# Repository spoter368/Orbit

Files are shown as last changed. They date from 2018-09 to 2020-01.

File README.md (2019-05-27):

# Orbit keyboard
A split ergonomic keyboard for all

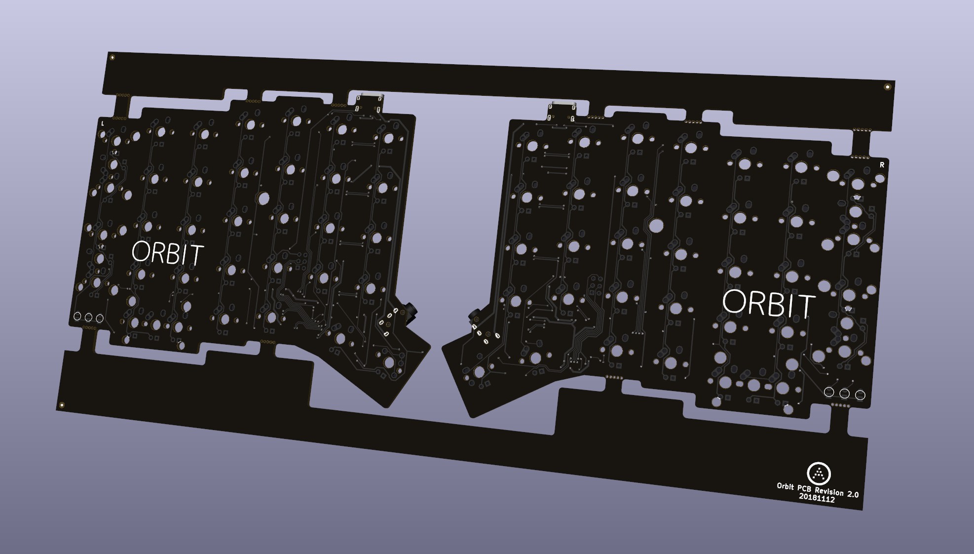
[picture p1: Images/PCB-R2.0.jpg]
Render Image


#### In light of recent claims that I am 100% liable for any of my open source PCBs, I am adding this disclaimer.
#### I provide these PCBs as a reference for designing keyboard PCBs. Using them within your projects will require a will to do research of one's own and to learn the workings of them, potentially fixing issues if they exist.
# I provide these PCBs without liability and without any guarantees regarding functionality, as expressed in the licenses under which these PCBs are licensed.

## Features
- Ergonomic layout based on the [crkbd](https://github.com/foostan/crkbd)
- All on-board components; no separate controller board
- USB Type-C and in-switch backlight
- Alps SKCL/M and MX compatibility
- Built-in overcurrent, reverse voltage, and ESD protection.
- Pre-panelized in a single PCB file for easy production
- Keyboard-Layout-Editor data is available [here](http://www.keyboard-layout-editor.com/#/gists/53ebf59524de12515cb7e2e6de94f0d6).

## Designed for all
- This keyboard remains close to typical QWERTY layout in key positioning.
- Most keys remain in their typical locations, which allows easy migration from standard layout keyboards.
- Whether new to ergonomic layouts or already an avid adopter, Orbit will suit your needs.

## Electrical side
- The incoming power is handled as shown:
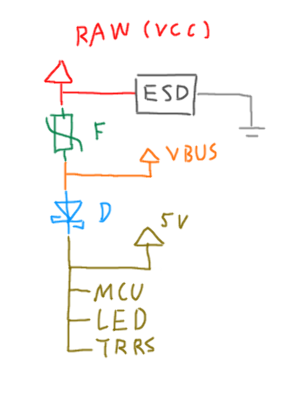
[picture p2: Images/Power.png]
Diagram

- VCC/Raw is the raw power fed through the USB connector. The ESD protection IC is bound to here.
- VBUS is "stable raw power" after being passed through a polyfuse. Used for upstream detection, for a downstream Schottky diode prevents flow from 5V into VBUS. In other words, VBUS is only at 5V when fed from upstream USB.
- 5V is the "stable power" after passing through a Schottky diode. Used for powering MCU, LEDs, and other split half. Power from the other half feeds here, for it has already been filtered on the other side.
- Measures are taken to isolate the LED, MCU, and split connection 5V as upstream as possible to prevent interference.

## Aesthetics
- Ground plane is limited to critical parts for aesthetic reasons.
- Top side of PCB is mostly covered with soldermask.

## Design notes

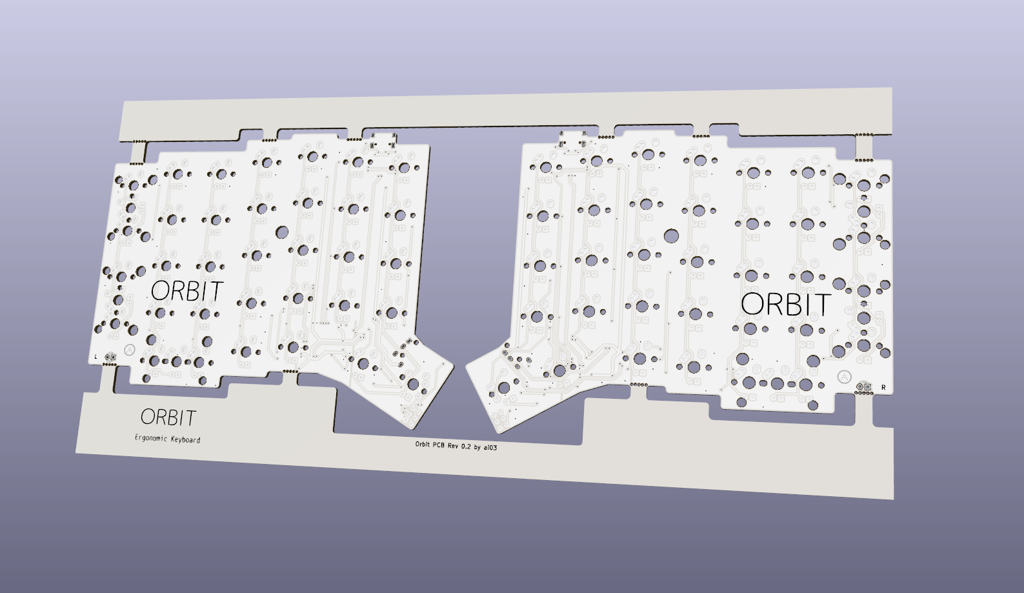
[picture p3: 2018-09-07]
Images/Render.png

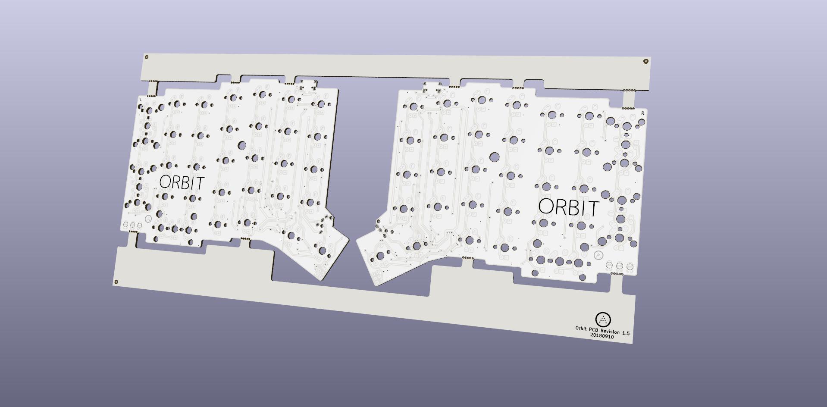
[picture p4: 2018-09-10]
Images/PCB-R1.5.jpg

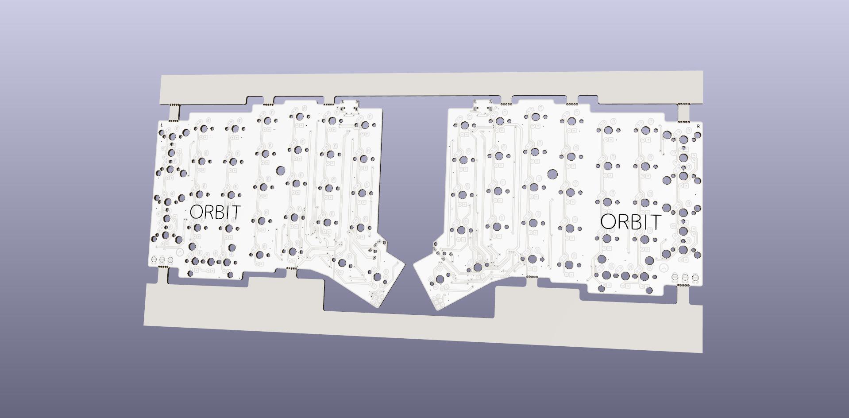
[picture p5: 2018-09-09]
Images/PCB-R1.2.jpg

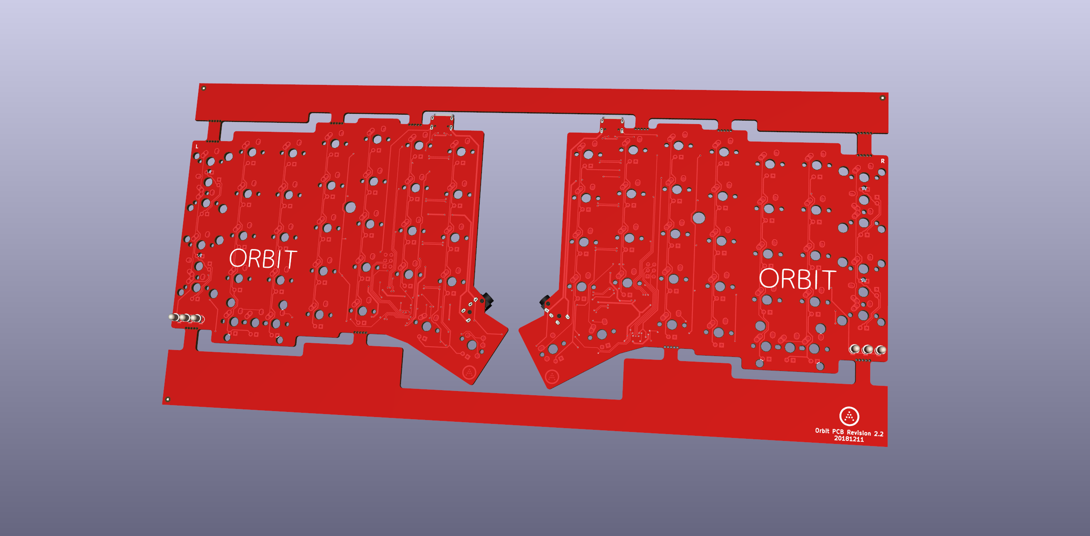
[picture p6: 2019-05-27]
Orbit-PCB/render.png

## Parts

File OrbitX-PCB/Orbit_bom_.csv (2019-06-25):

Component | Description | Part | References | Value | Footprint | Quantity Per PCB | Datasheet
1 | Unpolarized capacitor, small symbol | C_Small | C4 C5 C6 C11 C12 C13 | 0.1uF | C_0603_1608Metric | 6 | ~
2 | Unpolarized capacitor, small symbol | C_Small | C7 C14 | 10uF | C_0603_1608Metric | 2 | ~
3 | Unpolarized capacitor, small symbol | C_Small | C3 C10 | 1uF | C_0603_1608Metric | 2 | ~
4 | Unpolarized capacitor, small symbol | C_Small | C1 C2 C8 C9 | 22pF | C_0603_1608Metric | 4 | ~
5 | Diode, small symbol | D_Small | D1 D2 D3 D4 D5 D6 D7 D8 D9 D10 D11 D12 D13 D14 D15 D16 D17 D18 D19 D20 D21 D22 D23 D24 D25 D26 D27 D28 D29 D30 D31 D32 D33 D34 D35 D36 D37 D38 D39 D40 D41 D42 D43 D44 D45 D46 D47 D48 | SOD123 | D_SOD-123 | 48 | ~
6 | Schottky diode, small symbol | D_Schottky_Small | D75 D76 | Schottky | D_SOD-123 | 2 | ~
7 | Resettable fuse, polymeric positive temperature coefficient, small symbol | Polyfuse_Small | F1 F2 | 500mA | Fuse_1206_3216Metric | 2 | ~
8 | Generic connector, single row, 01x04, script generated (kicad-library-utils/schlib/autogen/connector/) | Conn_01x04 | J1 J11 | PJ-3200B-4A | PJ-3200B-4A | 2 | ~
9 | Resistor, small symbol | R_Small | R25 R67 R87 R88 | 10k | R_0603_1608Metric | 4 | ~
10 | Resistor, small symbol | R_Small | R41 R42 R83 R84 | 22 | R_0603_1608Metric | 4 | ~
11 | Resistor, small symbol | R_Small | R9 R10 | 4.7k | R_0603_1608Metric | 2 | ~
12 | Resistor, small symbol | R_Small | R43 R44 R85 R86 | 5.1k | R_0603_1608Metric | 4 | ~
13 | Push button switch, generic, two pins | SW_Push | SW1 SW2 | SW_Push | SKQGADE010 | 2
14 | 16MHz, 16kB Flash, 1.25kB SRAM, 512B EEPROM, USB 2.0, QFN-44 | ATmega32U4-MU | U1 U3 | ATmega32U4-MU | QFN-44-1EP_7x7mm_P0.5mm_EP5.2x5.2mm | 2 | http://ww1.microchip.com/downloads/en/DeviceDoc/Atmel-7766-8-bit-AVR-ATmega16U4-32U4_Datasheet.pdf
15 |  | PRTR5V0U2X | U2 U4 | PRTR5V0U2X | SOT143B | 2
16 |  | HRO-TYPE-C-31-M-12 | USB1 USB2 | HRO-TYPE-C-31-M-12 | HRO-TYPE-C-31-M-12-Assembly | 2
17 | Four pin crystal, GND on pins 2 and 4, small symbol | Crystal_GND24_Small | Y1 Y2 | 16MHz | Crystal_SMD_3225-4Pin_3.2x2.5mm | 2 | ~
Component Groups: | 17
Component Count: | 92
Fitted Components: | 92
Number of PCBs: | 1
Total components: | 92
Schematic Version:
Schematic Date:
BoM Date: | 6/25/2019 7:16:13 PM
Schematic Source: | C:\Users\Ryota\Documents\GitHub\Orbit\OrbitX-PCB\Orbit.sch
KiCad Version: | Eeschema (5.1.2)-1

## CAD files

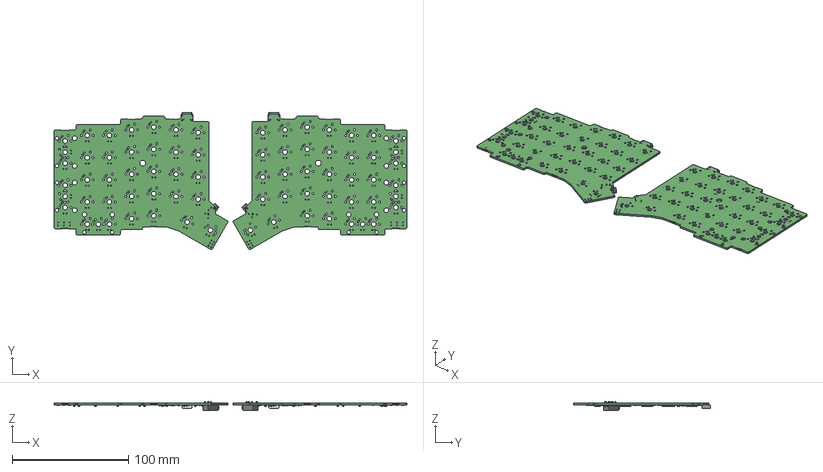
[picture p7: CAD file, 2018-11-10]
OrbitX-PCB/Orbit.step
303.2 x 117.9 x 8.00 mm

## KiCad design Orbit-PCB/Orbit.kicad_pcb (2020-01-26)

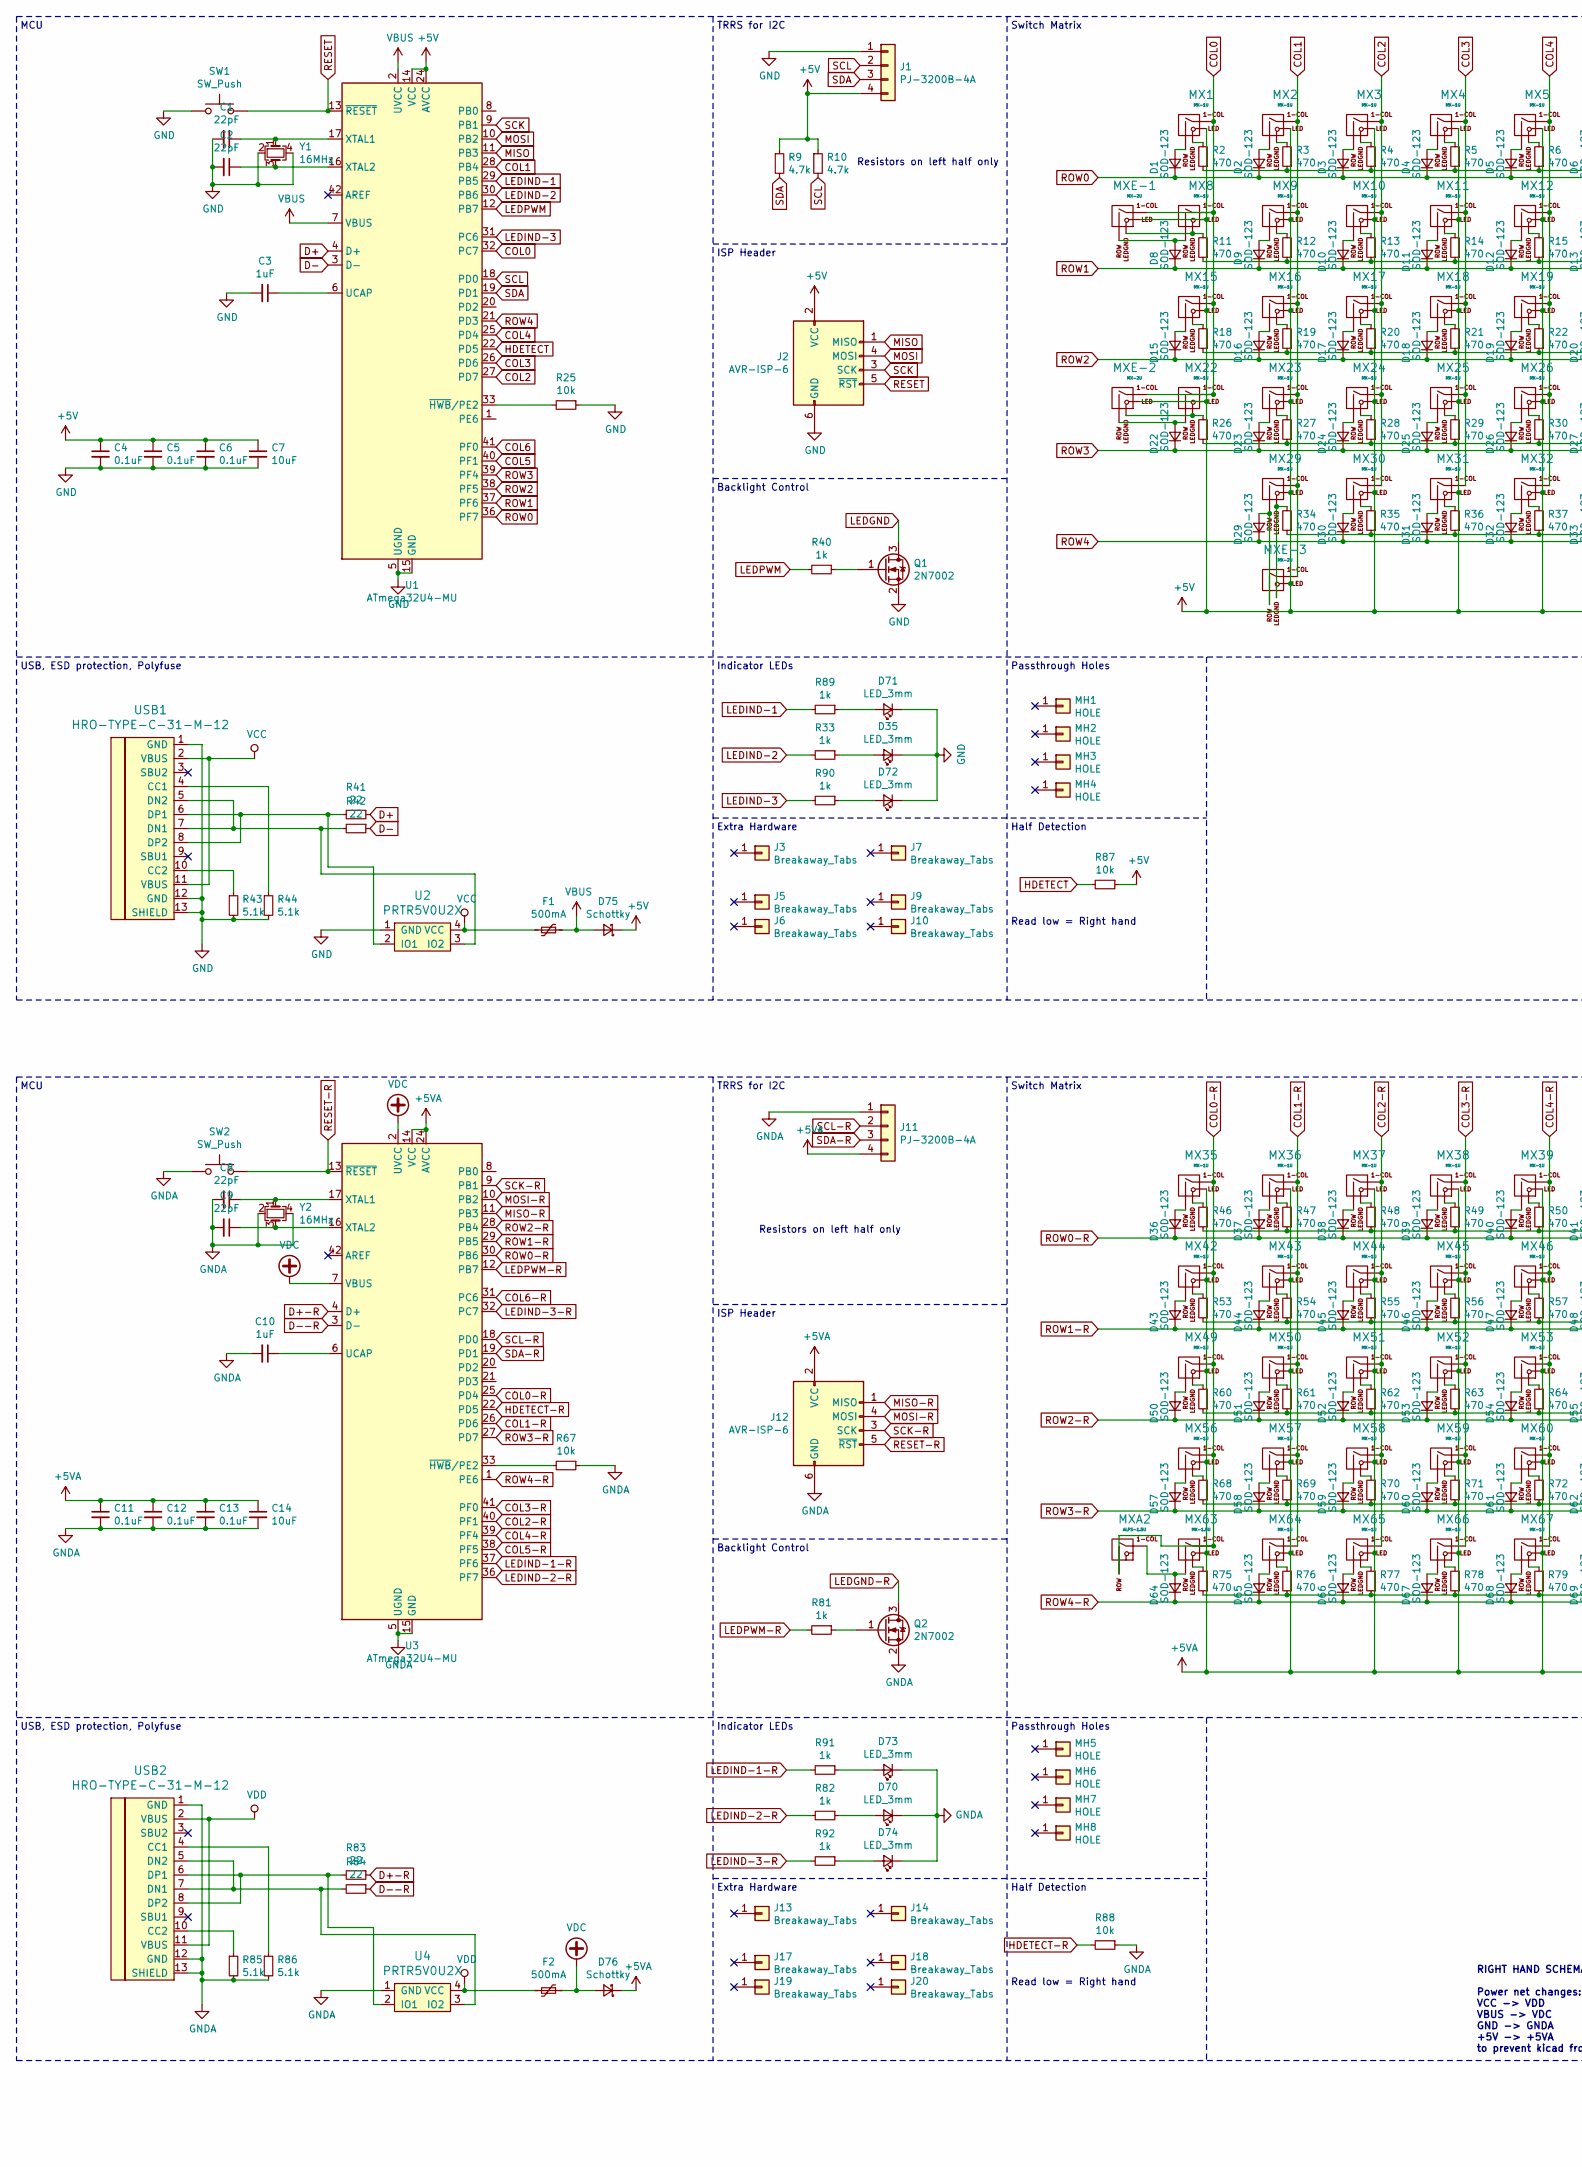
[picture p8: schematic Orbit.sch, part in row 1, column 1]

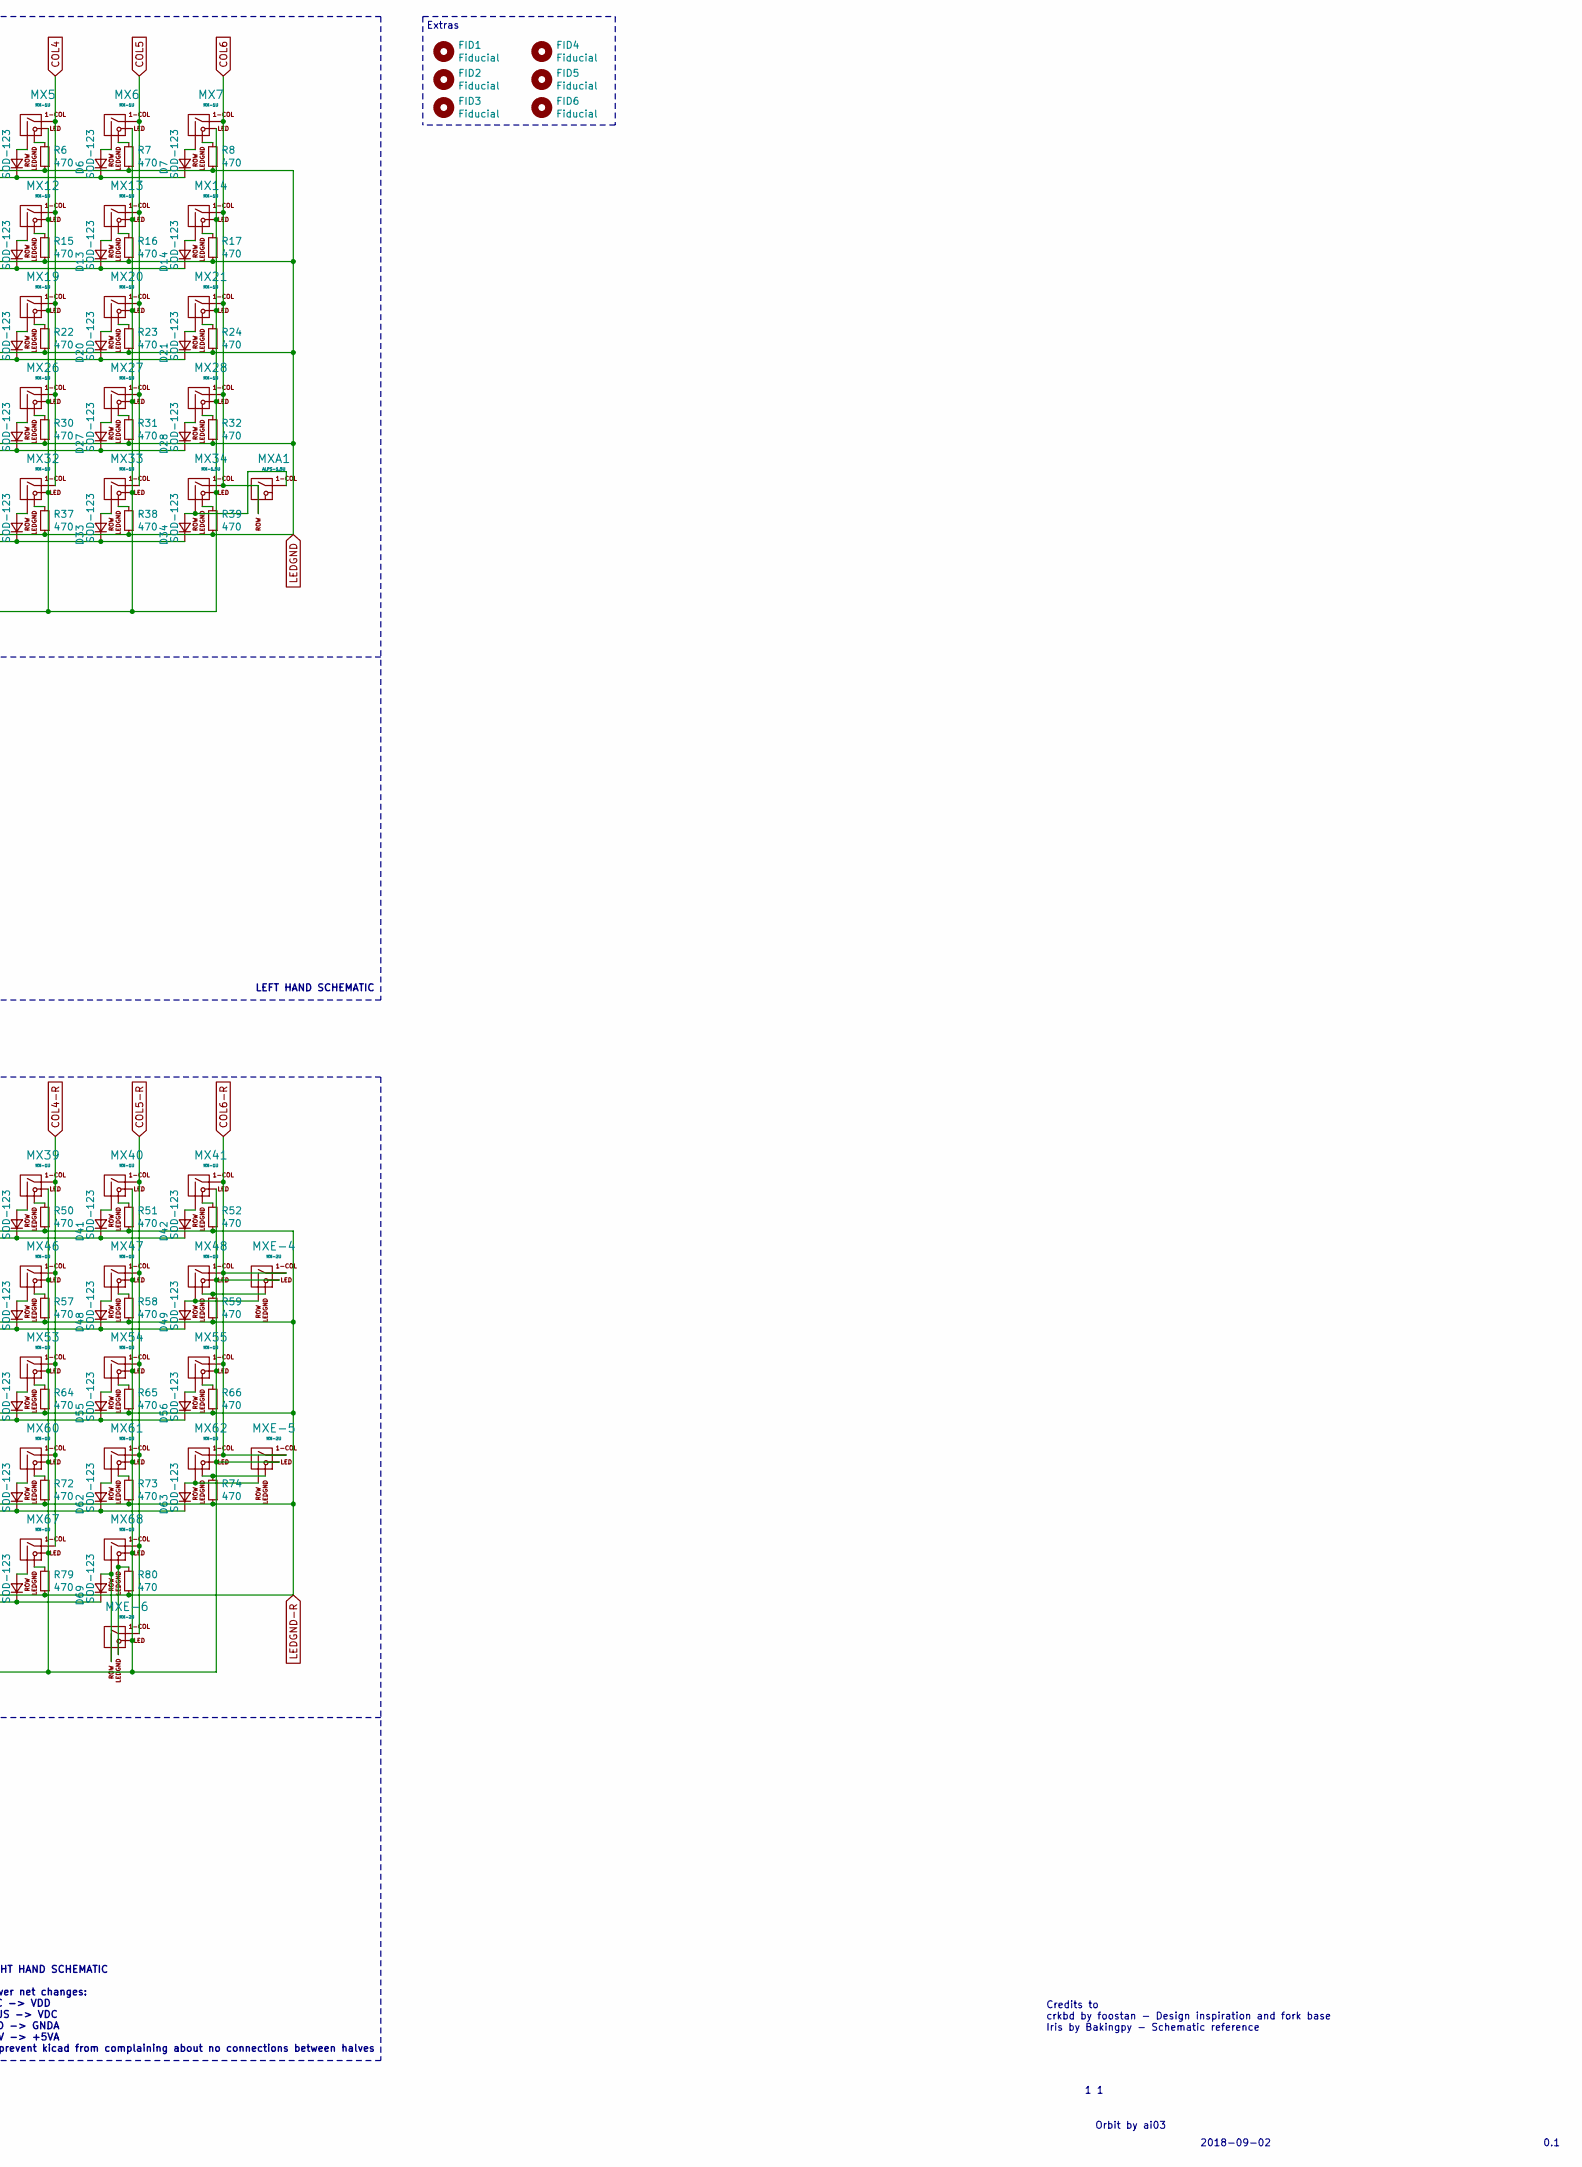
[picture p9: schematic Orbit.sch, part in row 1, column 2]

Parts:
C1, C2, C8, C9: 22pF; C_0603_1608Metric
C3, C10: 1uF; C_0603_1608Metric
C4, C5, C6, C11, C12, C13: 0.1uF; C_0603_1608Metric
C7, C14: 10uF; C_0603_1608Metric
D1, D2, D3, D4, D5, D6, D7, D8, D9, D10, D11, D12, D13, D14, D15, D16, D17, D18, D19, D20, D21, D22, D23, D24, D25, D26, D27, D28, D29, D30, D31, D32, D33, D34, D36, D37, D38, D39, D40, D41, D42, D43, D44, D45, D46, D47, D48, D49, D50, D51, D52, D53, D54, D55, D56, D57, D58, D59, D60, D61, D62, D63, D64, D65, D66, D67, D68, D69: SOD-123; D_SOD-123
D35, D70, D71, D72, D73, D74: LED_3mm; LED_D3.0mm
D75, D76: Schottky; D_SOD-123
F1, F2: 500mA; Fuse_SMD1206_Reflow
FID1, FID2, FID3, FID4, FID5, FID6: Fiducial; Fiducial_1mm_Dia_2.54mm_Outer_CopperTop
J1, J11: PJ-3200B-4A
J2, J12: AVR-ISP-6; Reset_Pretty
J3, J5, J6, J7, J9, J10, J13, J14, J17, J18, J19, J20: Breakaway_Tabs; breakaway-mousebites
MH1, MH2, MH3, MH4, MH5, MH6, MH7, MH8: HOLE; MountingHole_3.2mm_M3_ISO7380
MX1, MX2, MX3, MX4, MX5, MX6, MX7, MX8, MX9, MX10, MX11, MX12, MX13, MX14, MX15, MX16, MX17, MX18, MX19, MX20, MX21, MX22, MX23, MX24, MX25, MX26, MX27, MX28, MX29, MX30, MX31, MX32, MX33, MX35, MX36, MX37, MX38, MX39, MX40, MX41, MX42, MX43, MX44, MX45, MX46, MX47, MX48, MX49, MX50, MX51, MX52, MX53, MX54, MX55, MX56, MX57, MX58, MX59, MX60, MX61, MX62, MX64, MX65, MX66, MX67, MX68: MX-1U
MX34, MX63: MX-1.5U; MXOnly-1.5U-Vertical
MXA1, MXA2: ALPS-1.5U
MXE-1, MXE-2: MX-2U
MXE-3, MXE-4, MXE-5, MXE-6: MX-2U; MX-2U-ReversedStabilizers
Q1, Q2: 2N7002; SOT-23
R2, R3, R4, R5, R6, R7, R8, R11, R12, R13, R14, R15, R16, R17, R18, R19, R20, R21, R22, R23, R24, R26, R27, R28, R29, R30, R31, R32, R34, R35, R36, R37, R38, R39, R46, R47, R48, R49, R50, R51, R52, R53, R54, R55, R56, R57, R58, R59, R60, R61, R62, R63, R64, R65, R66, R68, R69, R70, R71, R72, R73, R74, R75, R76, R77, R78, R79, R80: 470; R_0805_2012Metric
R9, R10: 4.7k; R_0805_2012Metric
R25, R67, R87, R88: 10k; R_0805_2012Metric
R33, R40, R81, R82, R89, R90, R91, R92: 1k; R_0805_2012Metric
R41, R42, R83, R84: 22; R_0805_2012Metric
R43, R44, R85, R86: 5.1k; R_0805_2012Metric
SW1, SW2: SW_Push; SKQGADE010
U1, U3: ATmega32U4-MU; QFN-44-1EP_7x7mm_Pitch0.5mm
U2, U4: PRTR5V0U2X; SOT143B
USB1, USB2: HRO-TYPE-C-31-M-12; HRO-TYPE-C-31-M-12-Assembly
Y1, Y2: 16MHz; Crystal_SMD_3225-4pin_3.2x2.5mm

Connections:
+5V: C4.1, C5.1, C6.1, C7.1, D75.1 (K), J1.4, J2.2 (VCC), MX1.3 (LED), MX2.3 (LED), MX3.3 (LED), MX4.3 (LED), MX5.3 (LED), MX6.3 (LED), MX7.3 (LED), MX8.3 (LED), MX9.3 (LED), MX10.3 (LED), MX11.3 (LED), MX12.3 (LED), MX13.3 (LED), MX14.3 (LED), MX15.3 (LED), MX16.3 (LED), MX17.3 (LED), MX18.3 (LED), MX19.3 (LED), MX20.3 (LED), MX21.3 (LED), MX22.3 (LED), MX23.3 (LED), MX24.3 (LED), MX25.3 (LED), MX26.3 (LED), MX27.3 (LED), MX28.3 (LED), MX29.3 (LED), MX30.3 (LED), MX31.3 (LED), MX32.3 (LED), MX33.3 (LED), MX34.3 (LED), MXE-1.3 (LED), MXE-2.3 (LED), MXE-3.3 (LED), R9.1, R10.1, R87.1, U1.14 (VCC), U1.24 (AVCC), U1.34 (VCC), U1.44 (AVCC)
+5VA: C11.1, C12.1, C13.1, C14.1, D76.1 (K), J11.4, J12.2 (VCC), MX35.3 (LED), MX36.3 (LED), MX37.3 (LED), MX38.3 (LED), MX39.3 (LED), MX40.3 (LED), MX41.3 (LED), MX42.3 (LED), MX43.3 (LED), MX44.3 (LED), MX45.3 (LED), MX46.3 (LED), MX47.3 (LED), MX48.3 (LED), MX49.3 (LED), MX50.3 (LED), MX51.3 (LED), MX52.3 (LED), MX53.3 (LED), MX54.3 (LED), MX55.3 (LED), MX56.3 (LED), MX57.3 (LED), MX58.3 (LED), MX59.3 (LED), MX60.3 (LED), MX61.3 (LED), MX62.3 (LED), MX63.3 (LED), MX64.3 (LED), MX65.3 (LED), MX66.3 (LED), MX67.3 (LED), MX68.3 (LED), MXE-4.3 (LED), MXE-5.3 (LED), MXE-6.3 (LED), U3.14 (VCC), U3.24 (AVCC), U3.34 (VCC), U3.44 (AVCC)
COL0: MX1.1 (COL), MX8.1 (COL), MX15.1 (COL), MX22.1 (COL), MXE-1.1 (COL), MXE-2.1 (COL), U1.32 (PC7)
COL0-R: MX35.1 (COL), MX42.1 (COL), MX49.1 (COL), MX56.1 (COL), MX63.1 (COL), MXA2.2 (ROW), U3.25 (PD4)
COL1: MX2.1 (COL), MX9.1 (COL), MX16.1 (COL), MX23.1 (COL), MX29.1 (COL), MXE-3.1 (COL), U1.28 (PB4)
COL1-R: MX36.1 (COL), MX43.1 (COL), MX50.1 (COL), MX57.1 (COL), MX64.1 (COL), U3.26 (PD6)
COL2: MX3.1 (COL), MX10.1 (COL), MX17.1 (COL), MX24.1 (COL), MX30.1 (COL), U1.27 (PD7)
COL2-R: MX37.1 (COL), MX44.1 (COL), MX51.1 (COL), MX58.1 (COL), MX65.1 (COL), U3.40 (PF1)
COL3: MX4.1 (COL), MX11.1 (COL), MX18.1 (COL), MX25.1 (COL), MX31.1 (COL), U1.26 (PD6)
COL3-R: MX38.1 (COL), MX45.1 (COL), MX52.1 (COL), MX59.1 (COL), MX66.1 (COL), U3.41 (PF0)
COL4: MX5.1 (COL), MX12.1 (COL), MX19.1 (COL), MX26.1 (COL), MX32.1 (COL), U1.25 (PD4)
COL4-R: MX39.1 (COL), MX46.1 (COL), MX53.1 (COL), MX60.1 (COL), MX67.1 (COL), U3.39 (PF4)
COL5: MX6.1 (COL), MX13.1 (COL), MX20.1 (COL), MX27.1 (COL), MX33.1 (COL), U1.40 (PF1)
COL5-R: MX40.1 (COL), MX47.1 (COL), MX54.1 (COL), MX61.1 (COL), MX68.1 (COL), MXE-6.1 (COL), U3.38 (PF5)
COL6: MX7.1 (COL), MX14.1 (COL), MX21.1 (COL), MX28.1 (COL), MX34.1 (COL), MXA1.2 (ROW), U1.41 (PF0)
COL6-R: MX41.1 (COL), MX48.1 (COL), MX55.1 (COL), MX62.1 (COL), MXE-4.1 (COL), MXE-5.1 (COL), U3.31 (PC6)
D+: R41.1, U1.4 (D+)
D+-R: R83.1, U3.4 (D+)
D-: R42.1, U1.3 (D-)
D--R: R84.1, U3.3 (D-)
GND: C1.2, C2.2, C3.2, C4.2, C5.2, C6.2, C7.2, D35.1 (K), D71.1 (K), D72.1 (K), J1.1, J2.6 (GND), Q1.2 (S), R25.1, R43.2, R44.2, SW1.1, U1.5 (UGND), U1.15 (GND), U1.23 (GND), U1.35 (GND), U1.43 (GND), U1.45 (GND), U2.1 (GND), USB1.1 (GND), USB1.12 (GND), USB1.13 (SHIELD), Y1.2, Y1.4
GNDA: C8.2, C9.2, C10.2, C11.2, C12.2, C13.2, C14.2, D70.1 (K), D73.1 (K), D74.1 (K), J11.1, J12.6 (GND), Q2.2 (S), R67.1, R85.2, R86.2, R88.1, SW2.1, U3.5 (UGND), U3.15 (GND), U3.23 (GND), U3.35 (GND), U3.43 (GND), U3.45 (GND), U4.1 (GND), USB2.1 (GND), USB2.12 (GND), USB2.13 (SHIELD), Y2.2, Y2.4
HDETECT: R87.2, U1.22 (PD5)
HDETECT-R: R88.2, U3.22 (PD5)
LEDGND: Q1.3 (D), R2.1, R3.1, R4.1, R5.1, R6.1, R7.1, R8.1, R11.1, R12.1, R13.1, R14.1, R15.1, R16.1, R17.1, R18.1, R19.1, R20.1, R21.1, R22.1, R23.1, R24.1, R26.1, R27.1, R28.1, R29.1, R30.1, R31.1, R32.1, R34.1, R35.1, R36.1, R37.1, R38.1, R39.1
LEDGND-R: Q2.3 (D), R46.1, R47.1, R48.1, R49.1, R50.1, R51.1, R52.1, R53.1, R54.1, R55.1, R56.1, R57.1, R58.1, R59.1, R60.1, R61.1, R62.1, R63.1, R64.1, R65.1, R66.1, R68.1, R69.1, R70.1, R71.1, R72.1, R73.1, R74.1, R75.1, R76.1, R77.1, R78.1, R79.1, R80.1
LEDIND-1: R89.2, U1.29 (PB5)
LEDIND-1-R: R91.2, U3.37 (PF6)
LEDIND-2: R33.2, U1.30 (PB6)
LEDIND-2-R: R82.2, U3.36 (PF7)
LEDIND-3: R90.2, U1.31 (PC6)
LEDIND-3-R: R92.2, U3.32 (PC7)
LEDPWM: R40.2, U1.12 (PB7)
LEDPWM-R: R81.2, U3.12 (PB7)
MISO: J2.1 (MISO), U1.11 (PB3)
MISO-R: J12.1 (MISO), U3.11 (PB3)
MOSI: J2.4 (MOSI), U1.10 (PB2)
MOSI-R: J12.4 (MOSI), U3.10 (PB2)
unnamed: C1.1, U1.17 (XTAL1), Y1.1
unnamed: C2.1, U1.16 (XTAL2), Y1.3
unnamed: C3.1, U1.6 (UCAP)
unnamed: C8.1, U3.17 (XTAL1), Y2.1
unnamed: C9.1, U3.16 (XTAL2), Y2.3
unnamed: C10.1, U3.6 (UCAP)
unnamed: D1.2 (A), MX1.2 (ROW)
unnamed: D2.2 (A), MX2.2 (ROW)
unnamed: D3.2 (A), MX3.2 (ROW)
unnamed: D4.2 (A), MX4.2 (ROW)
unnamed: D5.2 (A), MX5.2 (ROW)
unnamed: D6.2 (A), MX6.2 (ROW)
unnamed: D7.2 (A), MX7.2 (ROW)
unnamed: D8.2 (A), MX8.2 (ROW), MXE-1.2 (ROW)
unnamed: D9.2 (A), MX9.2 (ROW)
unnamed: D10.2 (A), MX10.2 (ROW)
unnamed: D11.2 (A), MX11.2 (ROW)
unnamed: D12.2 (A), MX12.2 (ROW)
unnamed: D13.2 (A), MX13.2 (ROW)
unnamed: D14.2 (A), MX14.2 (ROW)
unnamed: D15.2 (A), MX15.2 (ROW)
unnamed: D16.2 (A), MX16.2 (ROW)
unnamed: D17.2 (A), MX17.2 (ROW)
unnamed: D18.2 (A), MX18.2 (ROW)
unnamed: D19.2 (A), MX19.2 (ROW)
unnamed: D20.2 (A), MX20.2 (ROW)
unnamed: D21.2 (A), MX21.2 (ROW)
unnamed: D22.2 (A), MX22.2 (ROW), MXE-2.2 (ROW)
unnamed: D23.2 (A), MX23.2 (ROW)
unnamed: D24.2 (A), MX24.2 (ROW)
unnamed: D25.2 (A), MX25.2 (ROW)
unnamed: D26.2 (A), MX26.2 (ROW)
unnamed: D27.2 (A), MX27.2 (ROW)
unnamed: D28.2 (A), MX28.2 (ROW)
unnamed: D29.2 (A), MX29.2 (ROW), MXE-3.2 (ROW)
unnamed: D30.2 (A), MX30.2 (ROW)
unnamed: D31.2 (A), MX31.2 (ROW)
unnamed: D32.2 (A), MX32.2 (ROW)
unnamed: D33.2 (A), MX33.2 (ROW)
unnamed: D34.2 (A), MX34.2 (ROW), MXA1.1 (COL)
unnamed: D35.2 (A), R33.1
unnamed: D36.2 (A), MX35.2 (ROW)
unnamed: D37.2 (A), MX36.2 (ROW)
unnamed: D38.2 (A), MX37.2 (ROW)
unnamed: D39.2 (A), MX38.2 (ROW)
unnamed: D40.2 (A), MX39.2 (ROW)
unnamed: D41.2 (A), MX40.2 (ROW)
unnamed: D42.2 (A), MX41.2 (ROW)
unnamed: D43.2 (A), MX42.2 (ROW)
unnamed: D44.2 (A), MX43.2 (ROW)
unnamed: D45.2 (A), MX44.2 (ROW)
unnamed: D46.2 (A), MX45.2 (ROW)
unnamed: D47.2 (A), MX46.2 (ROW)
unnamed: D48.2 (A), MX47.2 (ROW)
unnamed: D49.2 (A), MX48.2 (ROW), MXE-4.2 (ROW)
unnamed: D50.2 (A), MX49.2 (ROW)
unnamed: D51.2 (A), MX50.2 (ROW)
unnamed: D52.2 (A), MX51.2 (ROW)
unnamed: D53.2 (A), MX52.2 (ROW)
unnamed: D54.2 (A), MX53.2 (ROW)
unnamed: D55.2 (A), MX54.2 (ROW)
unnamed: D56.2 (A), MX55.2 (ROW)
unnamed: D57.2 (A), MX56.2 (ROW)
unnamed: D58.2 (A), MX57.2 (ROW)
unnamed: D59.2 (A), MX58.2 (ROW)
unnamed: D60.2 (A), MX59.2 (ROW)
unnamed: D61.2 (A), MX60.2 (ROW)
unnamed: D62.2 (A), MX61.2 (ROW)
unnamed: D63.2 (A), MX62.2 (ROW), MXE-5.2 (ROW)
unnamed: D64.2 (A), MX63.2 (ROW), MXA2.1 (COL)
unnamed: D65.2 (A), MX64.2 (ROW)
unnamed: D66.2 (A), MX65.2 (ROW)
unnamed: D67.2 (A), MX66.2 (ROW)
unnamed: D68.2 (A), MX67.2 (ROW)
unnamed: D69.2 (A), MX68.2 (ROW), MXE-6.2 (ROW)
unnamed: D70.2 (A), R82.1
unnamed: D71.2 (A), R89.1
unnamed: D72.2 (A), R90.1
unnamed: D73.2 (A), R91.1
unnamed: D74.2 (A), R92.1
unnamed: MX1.4 (LEDGND), R2.2
unnamed: MX2.4 (LEDGND), R3.2
unnamed: MX3.4 (LEDGND), R4.2
unnamed: MX4.4 (LEDGND), R5.2
unnamed: MX5.4 (LEDGND), R6.2
unnamed: MX6.4 (LEDGND), R7.2
unnamed: MX7.4 (LEDGND), R8.2
unnamed: MX8.4 (LEDGND), MXE-1.4 (LEDGND), R11.2
unnamed: MX9.4 (LEDGND), R12.2
unnamed: MX10.4 (LEDGND), R13.2
unnamed: MX11.4 (LEDGND), R14.2
unnamed: MX12.4 (LEDGND), R15.2
unnamed: MX13.4 (LEDGND), R16.2
unnamed: MX14.4 (LEDGND), R17.2
unnamed: MX15.4 (LEDGND), R18.2
unnamed: MX16.4 (LEDGND), R19.2
unnamed: MX17.4 (LEDGND), R20.2
unnamed: MX18.4 (LEDGND), R21.2
unnamed: MX19.4 (LEDGND), R22.2
unnamed: MX20.4 (LEDGND), R23.2
unnamed: MX21.4 (LEDGND), R24.2
unnamed: MX22.4 (LEDGND), MXE-2.4 (LEDGND), R26.2
unnamed: MX23.4 (LEDGND), R27.2
unnamed: MX24.4 (LEDGND), R28.2
unnamed: MX25.4 (LEDGND), R29.2
unnamed: MX26.4 (LEDGND), R30.2
unnamed: MX27.4 (LEDGND), R31.2
unnamed: MX28.4 (LEDGND), R32.2
unnamed: MX29.4 (LEDGND), MXE-3.4 (LEDGND), R34.2
unnamed: MX30.4 (LEDGND), R35.2
unnamed: MX31.4 (LEDGND), R36.2
unnamed: MX32.4 (LEDGND), R37.2
unnamed: MX33.4 (LEDGND), R38.2
unnamed: MX34.4 (LEDGND), R39.2
unnamed: MX35.4 (LEDGND), R46.2
unnamed: MX36.4 (LEDGND), R47.2
unnamed: MX37.4 (LEDGND), R48.2
unnamed: MX38.4 (LEDGND), R49.2
unnamed: MX39.4 (LEDGND), R50.2
unnamed: MX40.4 (LEDGND), R51.2
unnamed: MX41.4 (LEDGND), R52.2
unnamed: MX42.4 (LEDGND), R53.2
unnamed: MX43.4 (LEDGND), R54.2
unnamed: MX44.4 (LEDGND), R55.2
unnamed: MX45.4 (LEDGND), R56.2
unnamed: MX46.4 (LEDGND), R57.2
unnamed: MX47.4 (LEDGND), R58.2
unnamed: MX48.4 (LEDGND), MXE-4.4 (LEDGND), R59.2
unnamed: MX49.4 (LEDGND), R60.2
unnamed: MX50.4 (LEDGND), R61.2
unnamed: MX51.4 (LEDGND), R62.2
unnamed: MX52.4 (LEDGND), R63.2
unnamed: MX53.4 (LEDGND), R64.2
unnamed: MX54.4 (LEDGND), R65.2
unnamed: MX55.4 (LEDGND), R66.2
unnamed: MX56.4 (LEDGND), R68.2
unnamed: MX57.4 (LEDGND), R69.2
unnamed: MX58.4 (LEDGND), R70.2
unnamed: MX59.4 (LEDGND), R71.2
unnamed: MX60.4 (LEDGND), R72.2
unnamed: MX61.4 (LEDGND), R73.2
unnamed: MX62.4 (LEDGND), MXE-5.4 (LEDGND), R74.2
unnamed: MX63.4 (LEDGND), R75.2
unnamed: MX64.4 (LEDGND), R76.2
unnamed: MX65.4 (LEDGND), R77.2
unnamed: MX66.4 (LEDGND), R78.2
unnamed: MX67.4 (LEDGND), R79.2
unnamed: MX68.4 (LEDGND), MXE-6.4 (LEDGND), R80.2
unnamed: Q1.1 (G), R40.1
unnamed: Q2.1 (G), R81.1
unnamed: R25.2, U1.33 (~HWB~/PE2)
unnamed: R41.2, U2.2 (IO1), USB1.6 (DP1), USB1.8 (DP2)
unnamed: R42.2, U2.3 (IO2), USB1.5 (DN2), USB1.7 (DN1)
unnamed: R43.1, USB1.10 (CC2)
unnamed: R44.1, USB1.4 (CC1)
unnamed: R67.2, U3.33 (~HWB~/PE2)
unnamed: R83.2, U4.2 (IO1), USB2.6 (DP1), USB2.8 (DP2)
unnamed: R84.2, U4.3 (IO2), USB2.5 (DN2), USB2.7 (DN1)
unnamed: R85.1, USB2.10 (CC2)
unnamed: R86.1, USB2.4 (CC1)
RESET: J2.5 (~RST), SW1.2, U1.13 (~RESET)
RESET-R: J12.5 (~RST), SW2.2, U3.13 (~RESET)
ROW0: D1.1 (K), D2.1 (K), D3.1 (K), D4.1 (K), D5.1 (K), D6.1 (K), D7.1 (K), U1.36 (PF7)
ROW0-R: D36.1 (K), D37.1 (K), D38.1 (K), D39.1 (K), D40.1 (K), D41.1 (K), D42.1 (K), U3.30 (PB6)
ROW1: D8.1 (K), D9.1 (K), D10.1 (K), D11.1 (K), D12.1 (K), D13.1 (K), D14.1 (K), U1.37 (PF6)
ROW1-R: D43.1 (K), D44.1 (K), D45.1 (K), D46.1 (K), D47.1 (K), D48.1 (K), D49.1 (K), U3.29 (PB5)
ROW2: D15.1 (K), D16.1 (K), D17.1 (K), D18.1 (K), D19.1 (K), D20.1 (K), D21.1 (K), U1.38 (PF5)
ROW2-R: D50.1 (K), D51.1 (K), D52.1 (K), D53.1 (K), D54.1 (K), D55.1 (K), D56.1 (K), U3.28 (PB4)
ROW3: D22.1 (K), D23.1 (K), D24.1 (K), D25.1 (K), D26.1 (K), D27.1 (K), D28.1 (K), U1.39 (PF4)
ROW3-R: D57.1 (K), D58.1 (K), D59.1 (K), D60.1 (K), D61.1 (K), D62.1 (K), D63.1 (K), U3.27 (PD7)
ROW4: D29.1 (K), D30.1 (K), D31.1 (K), D32.1 (K), D33.1 (K), D34.1 (K), U1.21 (PD3)
ROW4-R: D64.1 (K), D65.1 (K), D66.1 (K), D67.1 (K), D68.1 (K), D69.1 (K), U3.1 (PE6)
SCK: J2.3 (SCK), U1.9 (PB1)
SCK-R: J12.3 (SCK), U3.9 (PB1)
SCL: J1.2, R10.2, U1.18 (PD0)
SCL-R: J11.2, U3.18 (PD0)
SDA: J1.3, R9.2, U1.19 (PD1)
SDA-R: J11.3, U3.19 (PD1)
VBUS: D75.2 (A), F1.1, U1.2 (UVCC), U1.7 (VBUS)
VCC: F1.2, U2.4 (VCC), USB1.2 (VBUS), USB1.11 (VBUS)
VDC: D76.2 (A), F2.1, U3.2 (UVCC), U3.7 (VBUS)
VDD: F2.2, U4.4 (VCC), USB2.2 (VBUS), USB2.11 (VBUS)

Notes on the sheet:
ISP Header
TRRS for I2C
MCU
USB, ESD protection, Polyfuse
Resistors on left half only
Backlight Control
Switch Matrix
Orbit by ai03
1 1
2018-09-02
0.1
Credits to crkbd by foostan - Design inspiration and fork base Iris by Bakingpy - Schematic reference
Indicator LEDs
Extra Hardware
LEFT HAND SCHEMATIC
RIGHT HAND SCHEMATIC Power net changes: VCC -> VDD VBUS -> VDC GND -> GNDA +5V -> +5VA to prevent kicad from complaining about no connections between halves
Passthrough Holes
Passthrough Holes
Half Detection
Read low = Right hand
Extras

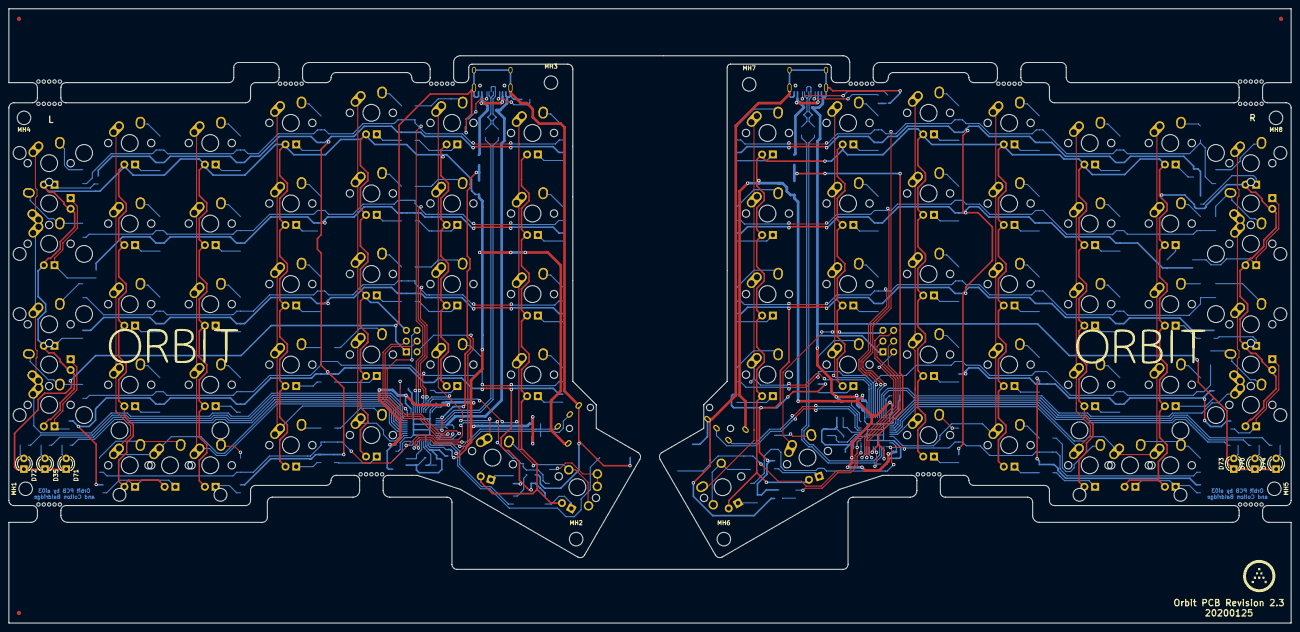
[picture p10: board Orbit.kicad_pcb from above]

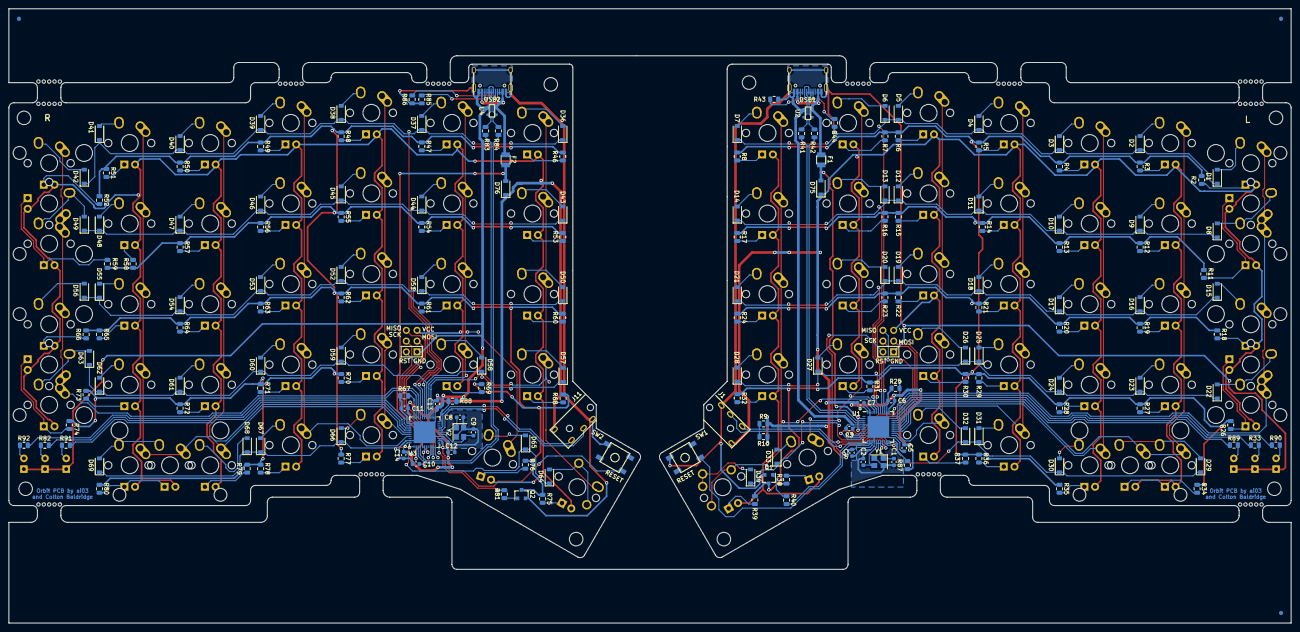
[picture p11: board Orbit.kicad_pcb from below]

Board: 2 copper layers, 303.2 x 145.3 mm, 300 parts (195 on the bottom side), 220 nets.

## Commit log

2018-09-01 Temporarily move project files
    [corne-cherry.kicad_pcb, corne-cherry.sch, corne-classic.kicad_pcb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]
2018-09-01 Add submodules
    [Orbit.kicad_pcb, Orbit.sch]
2018-09-01 Build a schematic
    [Orbit.sch]
2018-09-01 Assign footprints
    [Orbit.sch]
2018-09-06 Route one half
    [Orbit.kicad_pcb, Orbit.sch]
2018-09-06 Round corner and route indicator LED
    [Orbit.kicad_pcb, Orbit.sch]
2018-09-06 Both halves roughly complete, begin cleaning
    [Orbit.kicad_pcb, Orbit.sch]
2018-09-06 Reroute some traces
    [Orbit.kicad_pcb]
2018-09-06 Repair DRC errors
    [Orbit.kicad_pcb]
2018-09-06 Clean a few more traces
    [Orbit.kicad_pcb]
2018-09-06 Add left/right hand detection pullup/downs
    [Orbit.kicad_pcb, Orbit.sch]
2018-09-06 Clean a few tracks
    [Orbit.kicad_pcb]
2018-09-06 Wrong versioning
    [Orbit.kicad_pcb]
2018-09-06 Fix rail length, add dimensions
    [Orbit.kicad_pcb]
2018-09-07 Add 2U compat
    [Orbit.kicad_pcb, Orbit.sch]
2018-09-07 Reposition components to prevent stabilizer issues
    [Orbit.kicad_pcb]
2018-09-07 Prettify component labels
    [Orbit.kicad_pcb]
2018-09-07 Revision 0.2
    [Orbit.kicad_pcb]
2018-09-07 Aesthetic reroute and DRC error reduction
    [Orbit.kicad_pcb]
2018-09-07 Prettify LED power traces
    [Orbit.kicad_pcb]
2018-09-07 Fix 1.5U spacebar alps support
    [Orbit.kicad_pcb, Orbit.sch]
2018-09-07 Compact the panel slightly
    [Orbit.kicad_pcb]
2018-09-07 Simplify outline
    [Orbit.kicad_pcb]
2018-09-07 Fix trace too close to edge
    [Orbit.kicad_pcb]
2018-09-07 Move parts for easier soldering
    [Orbit.kicad_pcb]
2018-09-08 Move TRRS connector, too deep on most chassis
    [Orbit.kicad_pcb]
2018-09-09 Move TRRS further out
    [Orbit.kicad_pcb]
2018-09-09 Route status LEDs
    [Orbit.kicad_pcb, Orbit.sch]
2018-09-09 Adjust silkscreen
    [Orbit.kicad_pcb]
2018-09-09 Clean traces, finish silkscreen
    [Orbit.kicad_pcb]
2018-09-09 Beautify some traces
    [Orbit.kicad_pcb]
2018-09-09 Generate gerbers
    [Orbit-B.Cu.gbl, Orbit-B.Mask.gbs, Orbit-B.Paste.gbp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]
2018-09-09 Prepare for bom generation
    [Orbit.kicad_pcb]
2018-09-09 Generate generic bom
    [Orbit_bom_.csv]
2018-09-09 Clean BOM
    [Orbit.sch, Orbit_bom_.csv]
2018-09-09 Generate DXF; Attempt to generate position file
    [Orbit-B.Adhes.dxf, Orbit-B.Mask.dxf, Orbit-B.Paste.dxf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]
2018-09-10 Mark some footprints as virtual or SMD for sake of position file
    [Orbit.kicad_pcb, _saved_Orbit.sch]
2018-09-10 Slight routing tweaks
    [Orbit.kicad_pcb, Orbit.sch, _saved_Orbit.sch]
2018-09-10 Further routing tweaks
    [Orbit.kicad_pcb]
2018-09-10 Further tweaking, close to complete
    [Orbit.kicad_pcb]
2018-09-10 New gerbers and position files, prepare R1.5
    [Orbit-B.Cu.gbl, Orbit-B.Mask.gbs, Orbit-B.Paste.gbp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]
2018-09-25 Nudge just a few traces
    [Orbit.kicad_pcb]
2018-09-27 One tiny ground fill change
    Remove keepout from frontside which was placed by accident
    [Orbit.kicad_pcb]
2018-10-02 Move USB connectors outwards
    Prevent conflict with switches above
    [Orbit.kicad_pcb]
2018-10-12 Production adjustments
    [Orbit-B.Cu.gbl, Orbit-B.Mask.gbs, Orbit-B.Paste.gbp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]
2018-11-10 Update submodules
    [Orbit.kicad_pcb]
2018-11-10 Export step
    [Orbit.kicad_pcb, Orbit.step]
2018-11-11 Remove zones
    [Orbit.kicad_pcb]
2018-11-12 Continued progress
    [Orbit.kicad_pcb]
2018-11-12 Add schottky divide to vcc/vbus
    [Orbit.kicad_pcb, _saved_Orbit.sch]
2018-11-13 Finish routing
    [Orbit.kicad_pcb, Orbit.sch, _saved_Orbit.sch]
2018-11-13 Finish reroute
    [Orbit.kicad_pcb]
2018-11-13 Final touch
    [Orbit.kicad_pcb]
2018-11-13 Please commit properly this time
    [Orbit.kicad_pcb, _saved_Orbit.sch]
2018-11-13 Recovering lost progress
    [Orbit.kicad_pcb]
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2018-11-13 Further tuning
    [Orbit.kicad_pcb]
2018-11-13 Aesthetic tweaks, ready R2.0
    [Orbit.kicad_pcb]
2018-11-13 New production data
    [Orbit-B.Cu.gbl, Orbit-B.Mask.gbs, Orbit-B.Paste.gbp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]
2018-11-13 Generate new BOM
    [Orbit.sch, Orbit_bom_.csv]
2018-11-13 Update production data
    [OrbitQuote.xlsx]
2018-11-13 Add a comment
    [Orbit.sch]
2018-11-13 Add DC reverse ratings to production spec schottky
    [OrbitQuote.xlsx]
2018-11-13 Make it export USB position
    [Orbit.kicad_pcb]
2018-11-18 Tweak routing, move reset ever so slightly
    [Orbit-B.Cu.gbl, Orbit-B.Mask.gbs, Orbit-B.Paste.gbp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]
2018-11-18 Add description of power handling
    [Orbit.kicad_pcb]
2018-11-18 Tune routing
    [Orbit.kicad_pcb]
2018-11-18 Tune routing further
    [Orbit.kicad_pcb]
2018-11-18 Revision 2.0.1
    [Orbit-B.Cu.gbl, Orbit-B.Mask.gbs, Orbit-B.Paste.gbp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]
2018-11-18 Generate 2.1 production data
    [Orbit-B.Cu.gbl, Orbit-B.Mask.gbs, Orbit-B.Paste.gbp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]
2018-11-18 Correct crystal
    [OrbitQuote.xlsx]
2018-12-11 Update PCB to V2.2 - Differing pinout on each half
    [Orbit.kicad_pcb, Orbit.sch]
2018-12-11 Further tweak routing
    [Orbit.kicad_pcb]
2018-12-11 Fix some questionable design decisions
    [Orbit.kicad_pcb]
2018-12-13 Clean up decorations
    [Orbit.kicad_pcb]
2018-12-13 Generate Revision 2.2 production data
    [Orbit-B.Cu.gbl, Orbit-B.Mask.gbs, Orbit-B.Paste.gbp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]
2019-01-30 Add choc variant
    [Orbit-B.Adhes.dxf, Orbit-B.Mask.dxf, Orbit-B.Paste.dxf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]
2019-01-31 Build Orbit-C PCB for Choc switches
    [Orbit-B.Adhes.dxf, Orbit-B.Mask.dxf, Orbit-B.Paste.dxf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]
2019-01-31 Update traces
    [Orbit-B.Cu.gbl, Orbit-B.Mask.gbs, Orbit-B.Paste.gbp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]
2019-01-31 Adjust silkscren legends
    [Orbit-B.Cu.gbl, Orbit-B.Mask.gbs, Orbit-B.Paste.gbp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]
2019-06-25 Start work on OrbitX
    [Orbit.kicad_pcb, Orbit.sch, Orbit.step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]
2019-06-25 Place switches, draw outline
    [Orbit.kicad_pcb, Orbit.sch]
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2019-06-25 Add copper pour below USB
    [Orbit-B_Cu.gbl, Orbit-B_Mask.gbs, Orbit-B_Paste.gbp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]
2019-09-02 Fixed errors in board outline
    Opened in latest version of KiCAD and fized errors that prevented 3D view from showing properly
    [Orbit.kicad_pcb]
2020-01-26 Added mounting holes at the corners
    [Orbit.kicad_pcb, Orbit.sch]
